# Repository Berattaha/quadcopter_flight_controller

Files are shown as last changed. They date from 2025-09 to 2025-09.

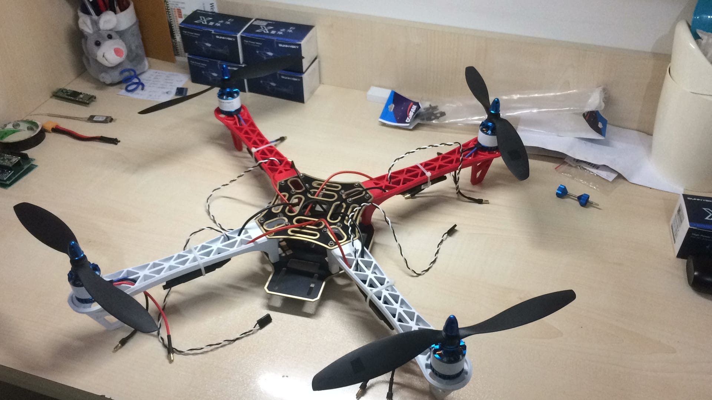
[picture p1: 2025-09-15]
images/Image1.jpeg

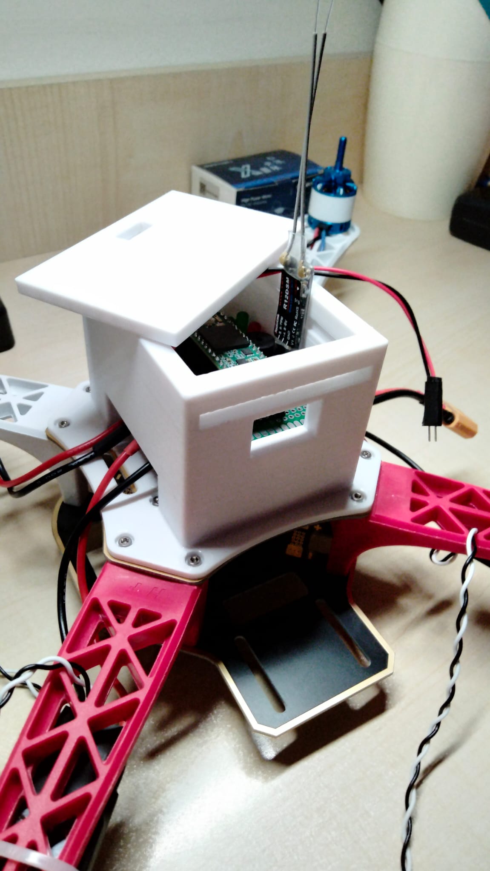
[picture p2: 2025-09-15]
images/Image2.jpeg

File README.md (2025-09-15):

# DIY Teensy/Arduino-Based Quadcopter Flight Controller

This repository contains the hardware and firmware design of a DIY quadcopter flight controller based on the Teensy 3.6 microcontroller.

## Background

This project was developed during my second year of college, during the COVID-19 pandemic. At the time, I had not yet taken a formal course in control theory. Therefore, the PID controller was not designed or simulated using MATLAB or similar tools.

Instead, I took a more hands-on approach:
- I built a small seesaw, mounted two motors at each end, and applied the **Ziegler-Nichols method** to find approximate PID values.
- It worked surprisingly well, and turned out to be a fun way to experiment with tuning.
- The quadcopter was flight-tested several times — and while it requires a bit of piloting skill, it flies well!

 A demo video can be found in the [YouTube Demo Video](https://youtube.com/shorts/SQsQxhgbjAk?feature=share) folder. 

---

## Features

- Sensor fusion from MPU6050 accelerometer and gyroscope data
- Simple PID-based stabilization algorithm tuned experimentally
- Teensy 3.6-based firmware written in Arduino IDE
- Manually tunde PID controller using a physical test rig and the Ziegler-Nichols method
- Basic safety indicators via buzzer and LEDs
- Lightweight custom 3D-printed enclosure for controller & power hub

---

## Mechanical Design

A compact case was designed and 3D-printed to hold both:
- The power hub (bottom section)
- The flight controller (top section)
- A snap-on lid

You can find the `.stl` file in the [`docs/`](docs) folder.

---

## Electronics & Wiring

Since I didn’t fabricate a PCB, I designed the schematic using **Fritzing**.  
It may not be the prettiest, but it gets the job done.

Required libraries are included in the [`libraries/`](libraries) folder.

---

## Components

### Flight Controller

- Teensy 3.6 (MK66FX1M0)
- MPU6050 (Accelerometer + Gyroscope)
- Mateksys MINI Power Hub w/ BEC (5V & 12V)
- 2x LEDs (with 3.3kΩ resistors)
- 1x Buzzer (with 100Ω resistor)
- 5x7 cm perfboard

### Quadcopter Frame

- Radiolink AT9s Pro + R12DSM Receiver
- DJI F450 Frame
- Sunnysky X2212 KV1250 3rd Gen x4
- Hobbywing XRotor 40A ESC x4
- Gemfan 9047 Propellers x4
- Profuse 11.1V 65C 1800 mAh LiPo battery

---

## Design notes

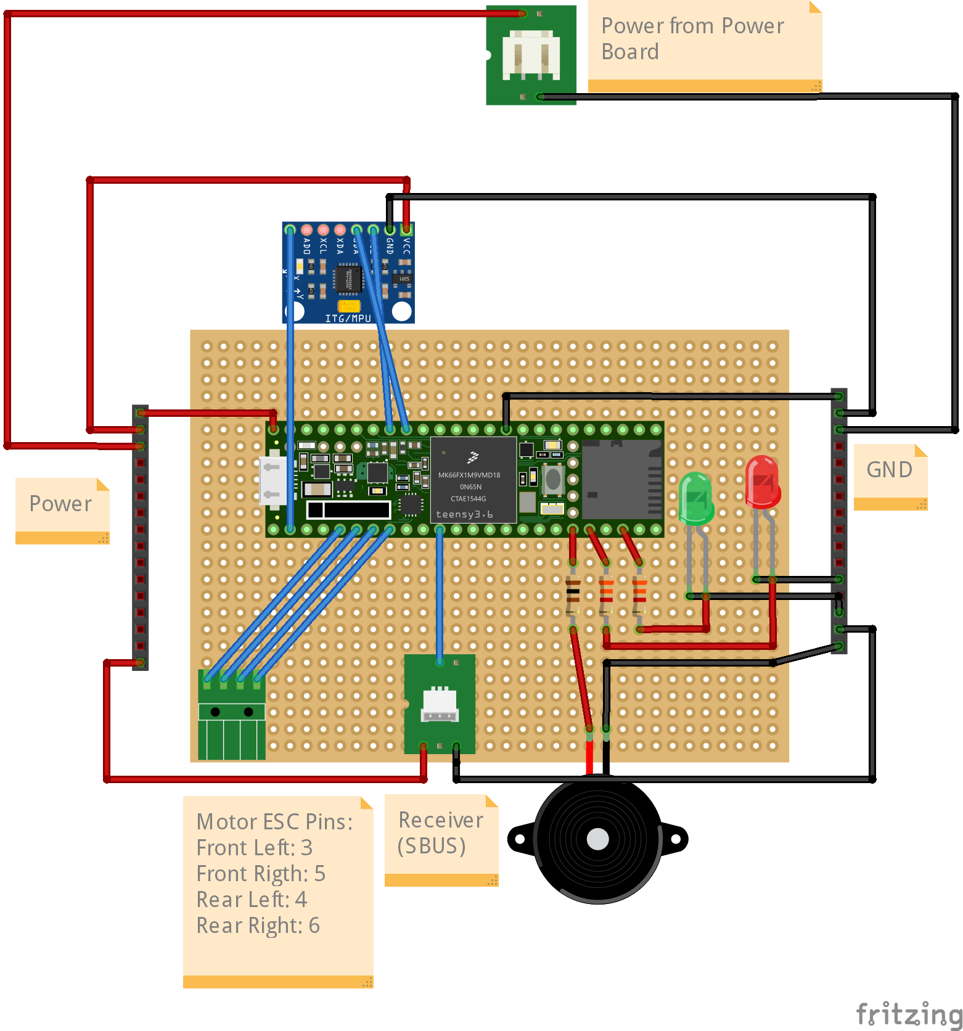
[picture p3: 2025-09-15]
docs/FlightController_bb.png

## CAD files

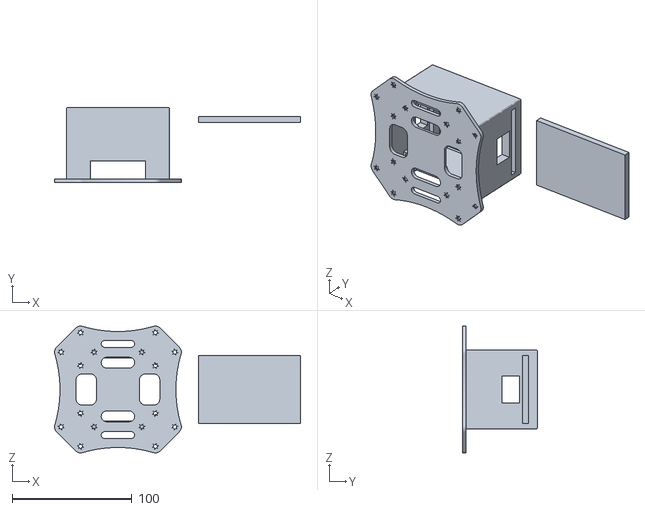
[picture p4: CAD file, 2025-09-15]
docs/drone aşama1 v4.stl
205.7 x 63.0 x 106.1

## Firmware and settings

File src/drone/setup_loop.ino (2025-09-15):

#include <avr/wdt.h>
void setup()
{
  wdt_enable(PROGRAM_TIMEOUT_IN_MILLISECONDS);

  /* Serial for printing the command */
 // Serial.begin(115200);
  initializeMotors();
  initializeOutputSignals();
  initializeReceiver();
  initializeIMU();
  LostFrame = 1;
  Failsafe = 1;


  quadcopter_initialization_completed();
}

void loop()
{
  wdt_reset();
  syncOutputSignals();
  
  struct ReceiverCommands receiverCommands = GetReceiverCommands();
  struct IMU_Values imu_values = GetIMUvalues();
  
  if(LostFrame != 0 || Failsafe !=0 ||  (receiverCommands.Throttle < THROTTLE_START_POINT) || !receiverCommands.Armed || imu_values.Error){
    stopMotors();
    resetPidVariables();
    return;
  }
   
  if(imu_values.NewDataAvailable){
  struct MotorPowers motorPowers = calculateMotorPowers(receiverCommands, imu_values);
  spinMotors(motorPowers);

   if( motorPowers.frontLeftMotorPower > 170 || motorPowers.frontRightMotorPower > 170 ||  motorPowers.rearLeftMotorPower > 170 || motorPowers.rearRightMotorPower > 170 ){
      stopMotors();
      resetPidVariables();
  }


      /*Serial.print(receiverCommands.RollAngle);
      Serial.print("\t");
      Serial.print(receiverCommands.PitchAngle);
      Serial.print("\t");
      Serial.print(receiverCommands.Throttle);
      Serial.print("\t");
      Serial.print(receiverCommands.YawAngleChange);
      Serial.print("\t");
    
     */ /*Serial.print(LostFrame);
      Serial.print("\t");
      Serial.println(Failsafe);
      Serial.print("\n");
      Serial.println(motorPowers.frontLeftMotorPower);
      //Serial.print("\t");
      Serial.println( motorPowers.frontRightMotorPower);
      //Serial.print("\t");
      Serial.println( motorPowers.rearLeftMotorPower);
      //Serial.print("\t");
      Serial.println(motorPowers.rearRightMotorPower);*/
  }
 
}  
  

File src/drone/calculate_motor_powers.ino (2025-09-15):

double roll_pid_i, roll_last_error, pitch_pid_i, pitch_last_error, yaw_pid_i, yaw_last_error;;
double roll_control_signal, pitch_control_signal, yaw_control_signal;

struct MotorPowers calculateMotorPowers(struct ReceiverCommands receiverCommands, struct IMU_Values imu_values) {
  // calculate orientation errors (error: difference between desired orientation and actual orientation)
  double rollError = receiverCommands.RollAngle - imu_values.CurrentOrientation.RollAngle;
  double pitchError = receiverCommands.PitchAngle - imu_values.CurrentOrientation.PitchAngle;
  double yawError = calculateYawError(receiverCommands, imu_values);

  // calculate control gains based on errors
  roll_control_signal = getControlSignal(rollError, KP_roll_pitch, KI_roll_pitch, KD_roll_pitch, roll_pid_i, roll_last_error, imu_values.DeltaTimeInSeconds);
  pitch_control_signal = getControlSignal(pitchError, KP_roll_pitch, KI_roll_pitch, KD_roll_pitch, pitch_pid_i, pitch_last_error, imu_values.DeltaTimeInSeconds);
  yaw_control_signal = getControlSignal(yawError, KP_yaw, KI_yaw, KD_yaw, yaw_pid_i, yaw_last_error, imu_values.DeltaTimeInSeconds);

  roll_control_signal = constrain(roll_control_signal, -ROLL_PITCH_CONTROL_SIGNAL_LIMIT, ROLL_PITCH_CONTROL_SIGNAL_LIMIT);
  pitch_control_signal = constrain(pitch_control_signal, -ROLL_PITCH_CONTROL_SIGNAL_LIMIT, ROLL_PITCH_CONTROL_SIGNAL_LIMIT);
 
  struct MotorPowers motorPowers;
  motorPowers.frontRightMotorPower = round(receiverCommands.Throttle - roll_control_signal + pitch_control_signal + yaw_control_signal);
  motorPowers.frontLeftMotorPower = round(receiverCommands.Throttle + roll_control_signal + pitch_control_signal - yaw_control_signal);
  motorPowers.rearRightMotorPower = round(receiverCommands.Throttle - roll_control_signal - pitch_control_signal - yaw_control_signal);
  motorPowers.rearLeftMotorPower = round(receiverCommands.Throttle + roll_control_signal - pitch_control_signal + yaw_control_signal);

  motorPowers = reduceMotorPowers(motorPowers);
  return motorPowers;
}

double calculateYawError(struct ReceiverCommands receiverCommands, struct IMU_Values imu_values) {
  double imuYawAngleChangeInDeltaTime = fix360degrees(imu_values.CurrentOrientation.YawAngle - imu_values.PreviousOrientation.YawAngle);
  double imuYawAngleChangePerSecond = imuYawAngleChangeInDeltaTime / imu_values.DeltaTimeInSeconds;
  double yawError = receiverCommands.YawAngleChange - imuYawAngleChangePerSecond;
  yawError = constrain(yawError, -QUADCOPTER_MAX_YAW_ANGLE_CHANGE_PER_SECOND, QUADCOPTER_MAX_YAW_ANGLE_CHANGE_PER_SECOND);
  return yawError;
}

struct MotorPowers reduceMotorPowers(MotorPowers motorPowers) { // to preserve balance if throttle limit exceeds the max value (180)
  int maxMotorPower = max(max(motorPowers.frontLeftMotorPower, motorPowers.frontRightMotorPower), max(motorPowers.rearLeftMotorPower, motorPowers.rearRightMotorPower));
  if (maxMotorPower > 180) {
    double power_reduction_rate = (double)maxMotorPower / (double)180;
    motorPowers.frontLeftMotorPower = round((double)motorPowers.frontLeftMotorPower / power_reduction_rate);
    motorPowers.frontRightMotorPower = round((double)motorPowers.frontRightMotorPower / power_reduction_rate);
    motorPowers.rearLeftMotorPower = round((double)motorPowers.rearLeftMotorPower / power_reduction_rate);
    motorPowers.rearRightMotorPower = round((double)motorPowers.rearRightMotorPower / power_reduction_rate);
  }
  return motorPowers;
}

void resetPidVariables() {
  roll_pid_i = 0;
  roll_last_error = 0;
  pitch_pid_i = 0;
  pitch_last_error = 0;
  yaw_pid_i = 0;
  yaw_last_error = 0;
  
}

double fix360degrees(double val) {
  if (val > 180) {
    return val - 360;
  } else if (val < -180) {
    return val + 360;
  } else {
    return val;
  }
}

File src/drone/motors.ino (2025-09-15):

#include <Servo.h>

Servo frontLeftMotor;
Servo frontRightMotor;
Servo rearLeftMotor;
Servo rearRightMotor;


void initializeMotors() {
  frontLeftMotor.attach(FRONT_LEFT_MOTOR_PIN, MIN_MOTOR_PULSE_WIDTH, MAX_MOTOR_PULSE_WIDTH);
  frontRightMotor.attach(FRONT_RIGHT_MOTOR_PIN, MIN_MOTOR_PULSE_WIDTH, MAX_MOTOR_PULSE_WIDTH);
  rearLeftMotor.attach(REAR_LEFT_MOTOR_PIN, MIN_MOTOR_PULSE_WIDTH, MAX_MOTOR_PULSE_WIDTH);
  rearRightMotor.attach(REAR_RIGHT_MOTOR_PIN, MIN_MOTOR_PULSE_WIDTH, MAX_MOTOR_PULSE_WIDTH);

  stopMotors();
}
void spinMotors(struct MotorPowers motorPowers) {
  frontLeftMotor.write(motorPowers.frontLeftMotorPower);
  frontRightMotor.write(motorPowers.frontRightMotorPower);
  rearLeftMotor.write(motorPowers.rearLeftMotorPower);
  rearRightMotor.write(motorPowers.rearRightMotorPower);
}

void stopMotors() {
  frontLeftMotor.write(0);
  frontRightMotor.write(0);
  rearLeftMotor.write(0);
  rearRightMotor.write(0);
}
